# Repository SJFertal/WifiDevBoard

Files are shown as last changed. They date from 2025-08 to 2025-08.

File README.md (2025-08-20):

STM32 based development board with 2.4Ghz communication capabilities

This board serves as my first experience with RF PCB design. This PCB has features such as: -Linear power regulation for low noise power supply -Proper impedance traces for RF and diff pair signal integrity -4 layers for consistent power plane coupling on signal layers 
-ESD protection for input signals 
-Proper antenna isolation 
-Signal layer ground pour and high stitching via count to reduce etching and improve coupling 
-Multiple GPIOs for application breadth 
MCU: STM32G47CB Transciever: NRF24L01P Regulator: LD1117

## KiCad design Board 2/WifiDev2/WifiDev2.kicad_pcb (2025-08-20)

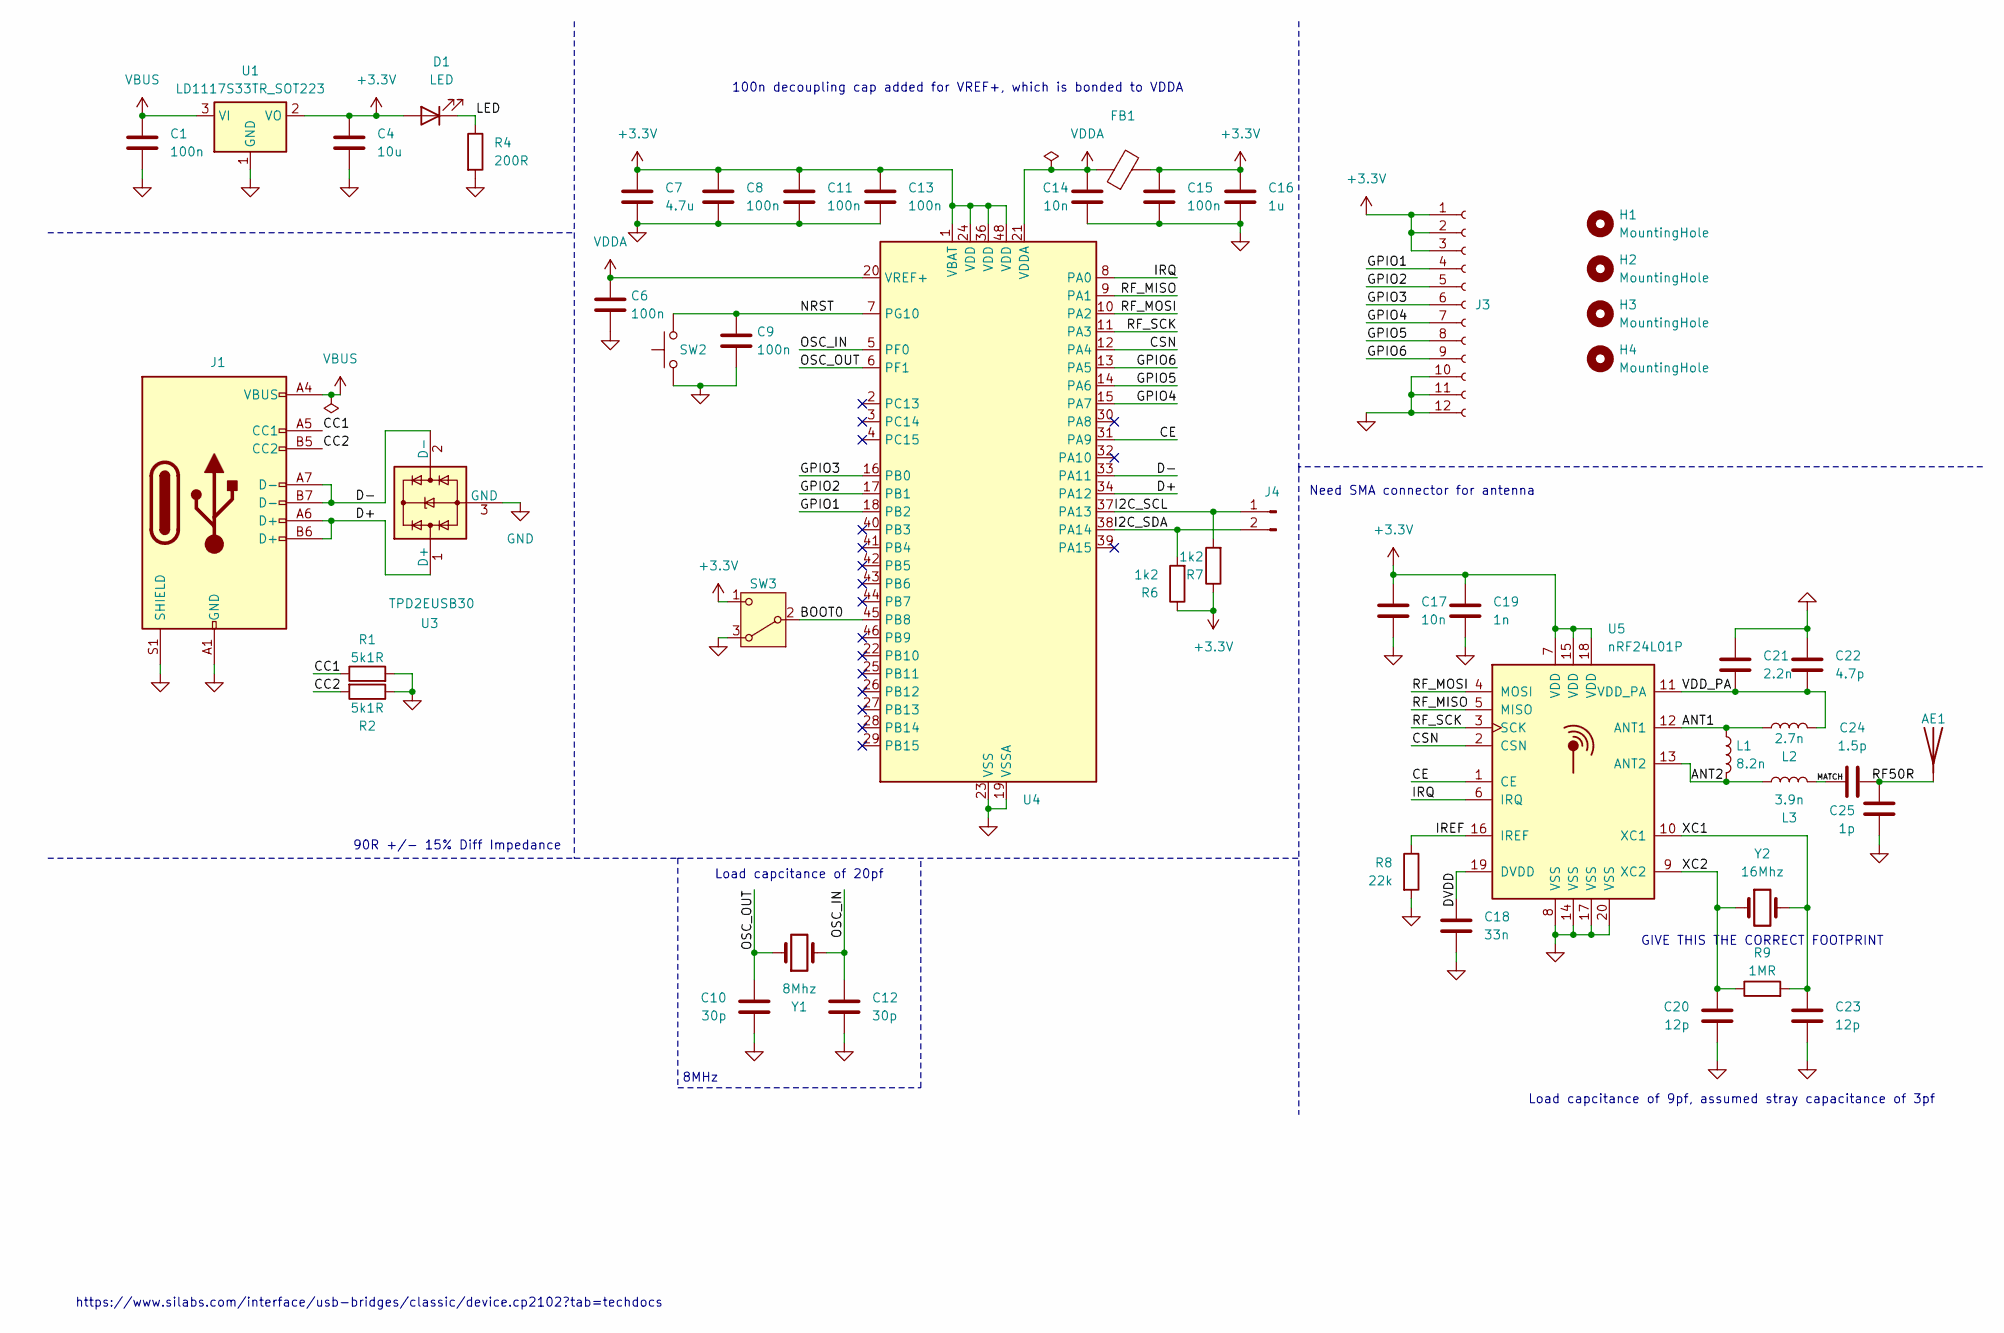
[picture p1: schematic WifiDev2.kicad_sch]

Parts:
AE1: Antenna; AMCA31-2R450G-S1F-T3
C1, C6, C8, C9, C11, C13, C15: 100n; C_0603_1608Metric
C4: 10u; C_0805_2012Metric
C7: 4.7u; C_0805_2012Metric
C10, C12: 30p; C_0603_1608Metric
C14, C17: 10n; C_0603_1608Metric
C16: 1u; C_0805_2012Metric
C18: 33n; C_0603_1608Metric
C19: 1n; C_0603_1608Metric
C20, C23: 12p; C_0603_1608Metric
C21: 2.2n; C_0603_1608Metric
C22: 4.7p; C_0603_1608Metric
C24: 1.5p; C_0603_1608Metric
C25: 1p; C_0603_1608Metric
D1: LED; LED_0603_1608Metric
FB1: FerriteBead; L_0603_1608Metric
H1, H2, H3, H4: MountingHole; MountingHole_2.2mm_M2_DIN965_Pad
J1: USB_C_Receptacle_USB2.0_14P; USB_C_Receptacle_G-Switch_GT-USB-7010ASV
J3: Conn_01x12_Socket; PinSocket_1x12_P2.54mm_Vertical
J4: Conn_01x02_Pin; PinHeader_1x02_P2.54mm_Vertical
L1: 8.2n; L_0603_1608Metric
L2: 2.7n; L_0603_1608Metric
L3: 3.9n; L_0603_1608Metric
R1, R2: 5k1R; R_0603_1608Metric
R4: 200R; R_0603_1608Metric
R6, R7: 1k2; R_0603_1608Metric
R8: 22k; R_0603_1608Metric
R9: 1MR; R_0805_2012Metric
SW2: SW_Push; SW_SPST_PTS647_Sx38
SW3: SW_Nidec_CAS-120A1; Nidec_Copal_CAS-120A
U1: LD1117S33TR_SOT223; SOT-223-3_TabPin2
U3: TPD2EUSB30; Texas_DRT-3
U4: STM32G4A1CETx; LQFP-48_7x7mm_P0.5mm
U5: nRF24L01P; QFN-20-1EP_4x4mm_P0.5mm_EP2.5x2.5mm
Y1: 8Mhz; Crystal_SMD_4Pin_3.2x2.5mm
Y2: 16Mhz; Crystal_SMD_4Pin_3.2x2.5mm

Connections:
+3.3V: C4.1, C7.1, C8.1, C11.1, C13.1, C15.1, C16.1, C17.1, C19.1, D1.2 (A), FB1.2, J3.1, J3.2, J3.3, R6.1, R7.1, SW3.1 (C), U1.2 (VO), U4.1 (VBAT), U4.24 (VDD), U4.36 (VDD), U4.48 (VDD), U5.7 (VDD), U5.15 (VDD), U5.18 (VDD)
/ANT1: L1.1, L2.2, U5.12 (ANT1)
/ANT2: L1.2, L3.2, U5.13 (ANT2)
/BOOT0: SW3.2 (B), U4.45 (PB8)
/CC1: J1.A5 (CC1), R1.1
/CC2: J1.B5 (CC2), R2.2
/CE: U4.31 (PA9), U5.1 (CE)
/CSN: U4.12 (PA4), U5.2 (CSN)
/D+: J1.A6 (D+), J1.B6 (D+), U3.1 (D+), U4.34 (PA12)
/D-: J1.A7 (D-), J1.B7 (D-), U3.2 (D-), U4.33 (PA11)
/DVDD: C18.1, U5.19 (DVDD)
/GPIO1: J3.4, U4.18 (PB2)
/GPIO2: J3.5, U4.17 (PB1)
/GPIO3: J3.6, U4.16 (PB0)
/GPIO4: J3.7, U4.15 (PA7)
/GPIO5: J3.8, U4.14 (PA6)
/GPIO6: J3.9, U4.13 (PA5)
/I2C_SCL: J4.1, R7.2, U4.37 (PA13)
/I2C_SDA: J4.2, R6.2, U4.38 (PA14)
/IREF: R8.1, U5.16 (IREF)
/IRQ: U4.8 (PA0), U5.6 (IRQ)
/LED: D1.1 (K), R4.1
/MATCH: C24.1, L3.1
/NRST: C9.1, SW2.2, U4.7 (PG10)
/OSC_IN: C12.1, U4.5 (PF0), Y1.2
/OSC_OUT: C10.1, U4.6 (PF1), Y1.1
/RF50R: AE1.1 (A), C24.2, C25.1
/RF_MISO: U4.9 (PA1), U5.5 (MISO)
/RF_MOSI: U4.10 (PA2), U5.4 (MOSI)
/RF_SCK: U4.11 (PA3), U5.3 (SCK)
/VDD_PA: C21.2, C22.2, L2.1, U5.11 (VDD_PA)
/XC1: C23.1, R9.2, U5.10 (XC1), Y2.2
/XC2: C20.1, R9.1, U5.9 (XC2), Y2.1
GND: C1.2, C4.2, C6.2, C7.2, C8.2, C9.2, C10.2, C11.2, C12.2, C13.2, C14.2, C15.2, C16.2, C17.2, C18.2, C19.2, C20.2, C21.1, C22.1, C23.2, C25.2, J1.A1 (GND), J1.A12 (GND), J1.B1 (GND), J1.B12 (GND), J1.S1 (SHIELD), J3.10, J3.11, J3.12, R1.2, R2.1, R4.2, R8.2, SW2.1, SW3.3 (A), U1.1 (GND), U3.3 (GND), U4.19 (VSSA), U4.23 (VSS), U4.35 (VSS), U4.47 (VSS), U5.8 (VSS), U5.14 (VSS), U5.17 (VSS), U5.20 (VSS)
VBUS: C1.1, J1.A4 (VBUS), J1.A9 (VBUS), J1.B4 (VBUS), J1.B9 (VBUS), U1.3 (VI)
VDDA: C6.1, C14.1, FB1.1, U4.20 (VREF+), U4.21 (VDDA)

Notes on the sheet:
https://www.silabs.com/interface/usb-bridges/classic/device.cp2102?tab=techdocs
GIVE THIS THE CORRECT FOOTPRINT
8MHz
Need SMA connector for antenna
90R +/- 15% Diff Impedance
Load capcitance of 9pf, assumed stray capacitance of 3pf
100n decoupling cap added for VREF+, which is bonded to VDDA
Load capcitance of 20pf

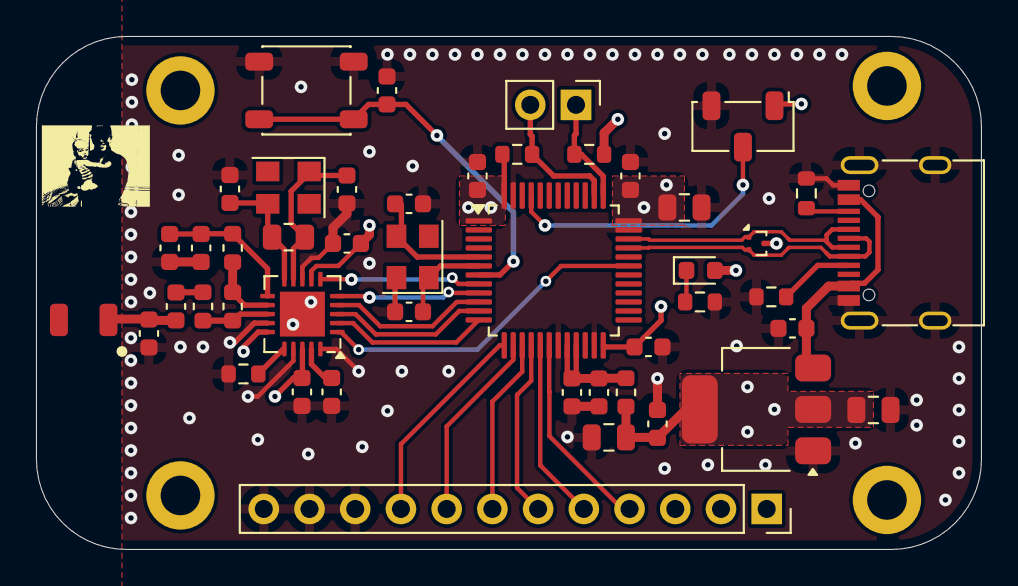
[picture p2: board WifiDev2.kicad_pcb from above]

Board: 4 copper layers, 52.5 x 28.5 mm, 50 parts (0 on the bottom side), 36 nets.

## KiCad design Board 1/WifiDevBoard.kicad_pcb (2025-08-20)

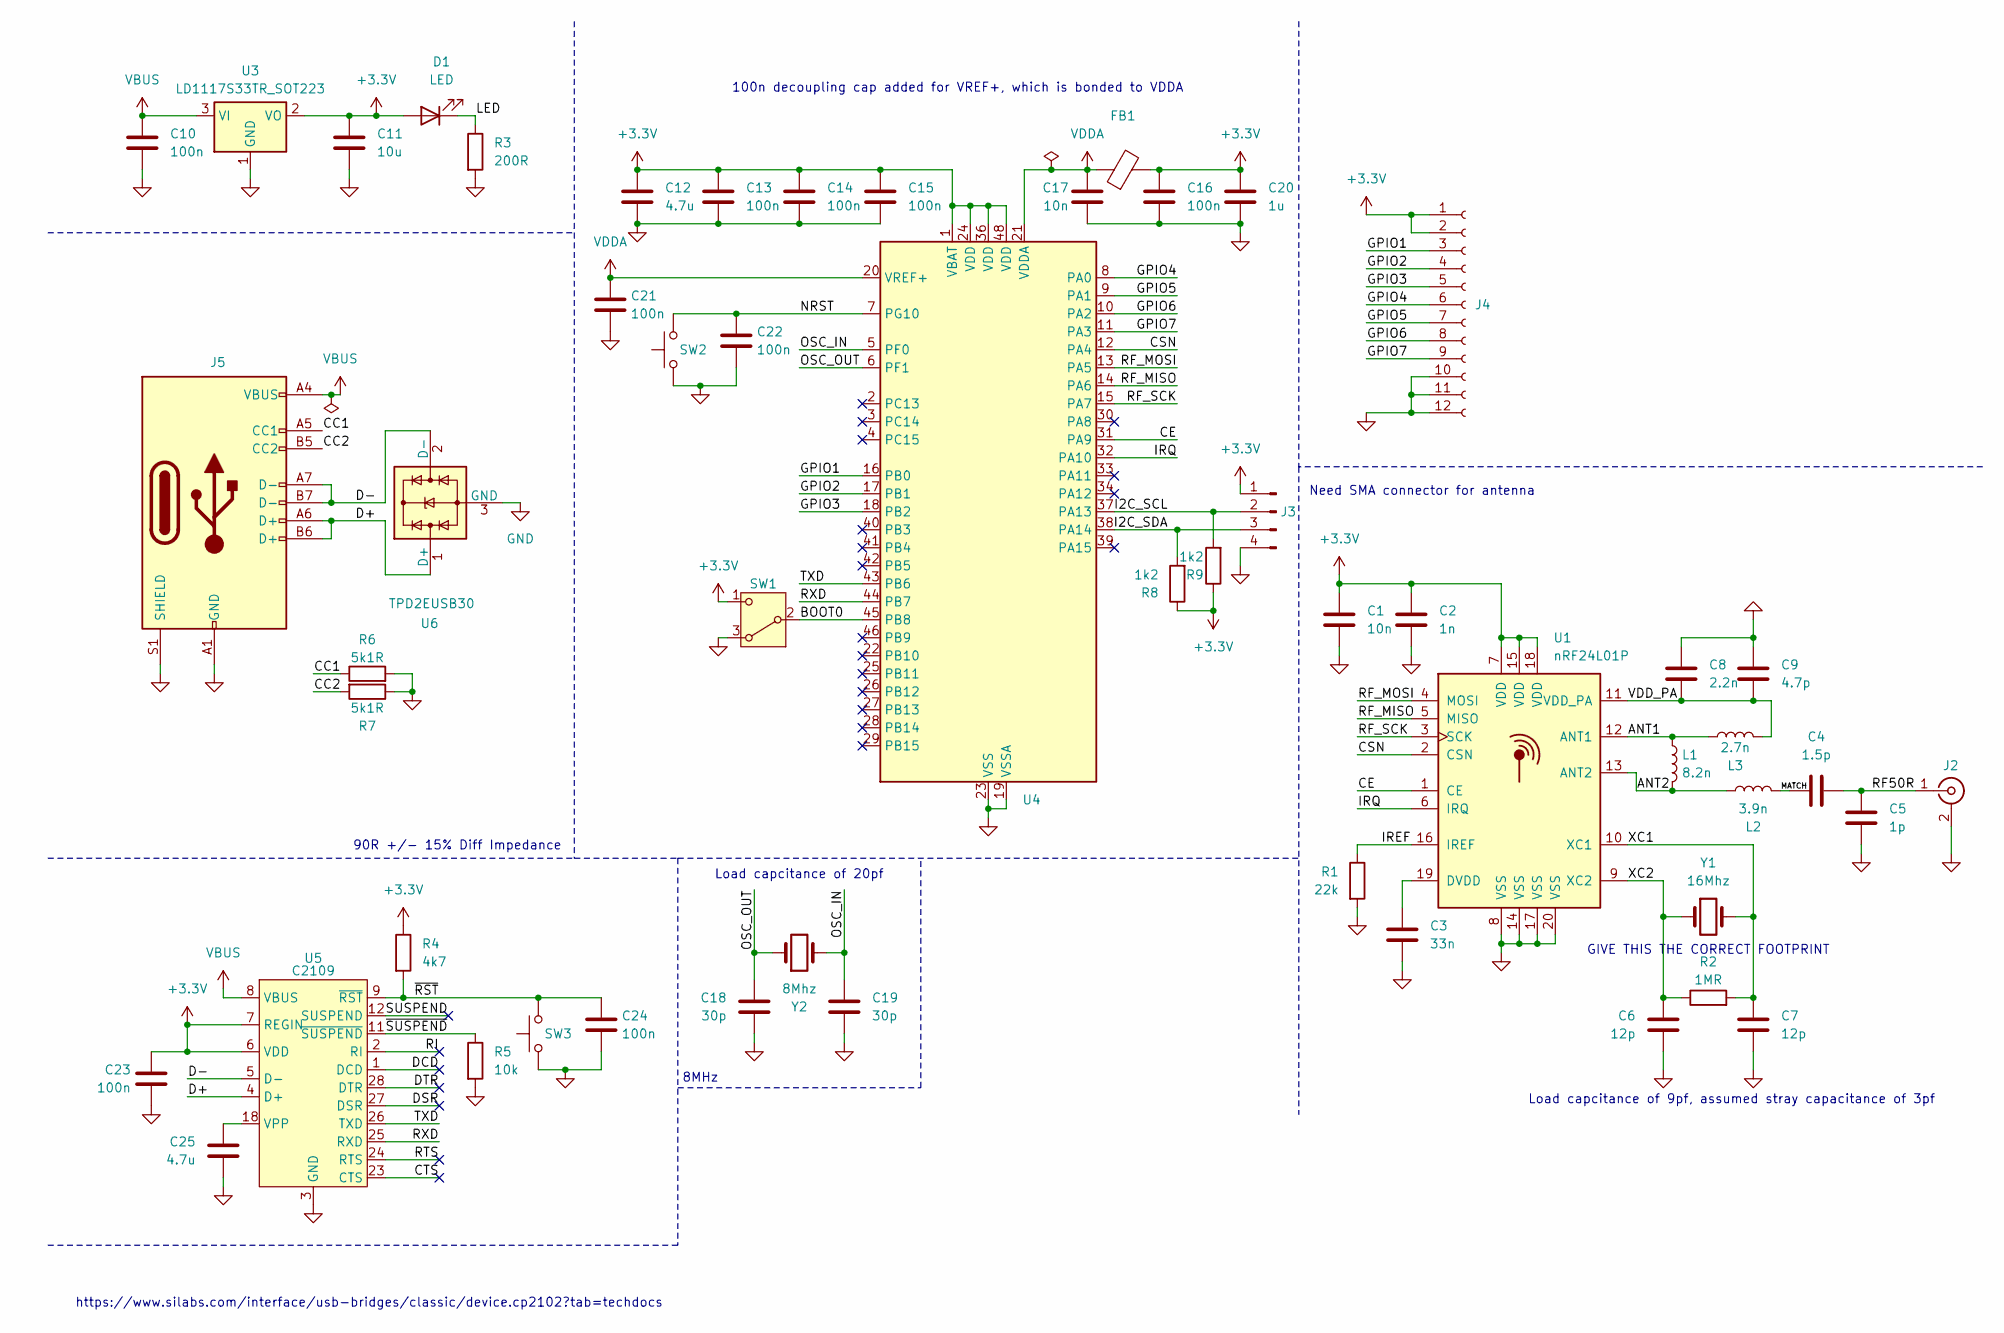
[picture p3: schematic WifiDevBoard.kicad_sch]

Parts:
C1, C17: 10n; C_0603_1608Metric
C2: 1n; C_0603_1608Metric
C3: 33n; C_0603_1608Metric
C4: 1.5p; C_0603_1608Metric
C5: 1p; C_0603_1608Metric
C6, C7: 12p; C_0603_1608Metric
C8: 2.2n; C_0603_1608Metric
C9: 4.7p; C_0603_1608Metric
C10, C13, C14, C15, C16, C21, C22, C23, C24: 100n; C_0603_1608Metric
C11: 10u; C_0805_2012Metric
C12, C25: 4.7u; C_0805_2012Metric
C18, C19: 30p; C_0603_1608Metric
C20: 1u; C_0805_2012Metric
D1: LED; LED_0603_1608Metric
FB1: FerriteBead; L_0603_1608Metric
J2: https://www.mouser.com/ProductDetail/GCT/RFPC-SMA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; SMA_Amphenol_901-144_Vertical
J3: Conn_01x04_Pin; JST_EH_B4B-EH-A_1x04_P2.50mm_Vertical
J4: Conn_01x12_Socket; PinSocket_1x12_P2.54mm_Vertical
J5: USB_C_Receptacle_USB2.0_14P; USB_C_Receptacle_G-Switch_GT-USB-7010ASV
L1: 8.2n; L_0603_1608Metric
L2: 3.9n; L_0603_1608Metric
L3: 2.7n; L_0603_1608Metric
R1: 22k; R_0805_2012Metric
R2: 1MR; R_0805_2012Metric
R3: 200R; R_0805_2012Metric
R4: 4k7; R_0805_2012Metric
R5: 10k; R_0805_2012Metric
R6, R7: 5k1R; R_0805_2012Metric
R8, R9: 1k2; R_0805_2012Metric
SW1: SW_Nidec_CAS-120A1; Nidec_Copal_CAS-120A
SW2, SW3: SW_Push; SW_SPST_PTS647_Sx38
U1: nRF24L01P; QFN-20-1EP_4x4mm_P0.5mm_EP2.5x2.5mm
U3: LD1117S33TR_SOT223; SOT-223-3_TabPin2
U4: STM32G4A1CETx; LQFP-48_7x7mm_P0.5mm
U5: C2109; QFN-28-1EP_5x5mm_P0.5mm_EP3.1x3.1mm
U6: TPD2EUSB30; Texas_DRT-3
Y1: 16Mhz; Crystal_SMD_4Pin_3.2x2.5mm
Y2: 8Mhz; Crystal_SMD_4Pin_3.2x2.5mm

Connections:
+3.3V: C1.1, C2.1, C11.1, C12.1, C13.1, C14.1, C15.1, C16.1, C20.1, C23.1, D1.2 (A), FB1.2, J3.1, J4.1, J4.2, R4.1, R8.1, R9.1, SW1.1 (C), U1.7 (VDD), U1.15 (VDD), U1.18 (VDD), U3.2 (VO), U4.1 (VBAT), U4.24 (VDD), U4.36 (VDD), U4.48 (VDD), U5.6 (VDD), U5.7 (REGIN)
/ANT1: L1.1, L3.2, U1.12 (ANT1)
/ANT2: L1.2, L2.2, U1.13 (ANT2)
/BOOT0: SW1.2 (B), U4.45 (PB8)
/CC1: J5.A5 (CC1), R6.1
/CC2: J5.B5 (CC2), R7.2
/CE: U1.1 (CE), U4.31 (PA9)
/CSN: U1.2 (CSN), U4.12 (PA4)
/CTS: U5.23 (CTS)
/D+: J5.A6 (D+), J5.B6 (D+), U5.4 (D+), U6.1 (D+)
/D-: J5.A7 (D-), J5.B7 (D-), U5.5 (D-), U6.2 (D-)
/DCD: U5.1 (DCD)
/DSR: U5.27 (DSR)
/DTR: U5.28 (DTR)
/GPIO1: J4.3, U4.16 (PB0)
/GPIO2: J4.4, U4.17 (PB1)
/GPIO3: J4.5, U4.18 (PB2)
/GPIO4: J4.6, U4.8 (PA0)
/GPIO5: J4.7, U4.9 (PA1)
/GPIO6: J4.8, U4.10 (PA2)
/GPIO7: J4.9, U4.11 (PA3)
/I2C_SCL: J3.2, R9.2, U4.37 (PA13)
/I2C_SDA: J3.3, R8.2, U4.38 (PA14)
/IREF: R1.1, U1.16 (IREF)
/IRQ: U1.6 (IRQ), U4.32 (PA10)
/LED: D1.1 (K), R3.1
/MATCH: C4.1, L2.1
/NRST: C22.1, SW2.2, U4.7 (PG10)
/OSC_IN: C19.1, U4.5 (PF0), Y2.2
/OSC_OUT: C18.1, U4.6 (PF1), Y2.1
/RF50R: C4.2, C5.1, J2.1 (In)
/RF_MISO: U1.5 (MISO), U4.14 (PA6)
/RF_MOSI: U1.4 (MOSI), U4.13 (PA5)
/RF_SCK: U1.3 (SCK), U4.15 (PA7)
/RI: U5.2 (RI)
/RTS: U5.24 (RTS)
/RXD: U4.44 (PB7), U5.25 (RXD)
/SUSPEND: U5.12 (SUSPEND)
/TXD: U4.43 (PB6), U5.26 (TXD)
/VDD_PA: C8.2, C9.2, L3.1, U1.11 (VDD_PA)
/XC1: C7.1, R2.2, U1.10 (XC1), Y1.2
/XC2: C6.1, R2.1, U1.9 (XC2), Y1.1
/~RST: C24.1, R4.2, SW3.2, U5.9 (~RST)
/~SUSPEND: R5.1, U5.11 (~SUSPEND)
GND: C1.2, C2.2, C3.2, C5.2, C6.2, C7.2, C8.1, C9.1, C10.2, C11.2, C12.2, C13.2, C14.2, C15.2, C16.2, C17.2, C18.2, C19.2, C20.2, C21.2, C22.2, C23.2, C24.2, C25.2, J2.2 (Ext), J3.4, J4.10, J4.11, J4.12, J5.A1 (GND), J5.A12 (GND), J5.B1 (GND), J5.B12 (GND), J5.S1 (SHIELD), R1.2, R3.2, R5.2, R6.2, R7.1, SW1.3 (A), SW2.1, SW3.1, U1.8 (VSS), U1.14 (VSS), U1.17 (VSS), U1.20 (VSS), U3.1 (GND), U4.19 (VSSA), U4.23 (VSS), U4.35 (VSS), U4.47 (VSS), U5.3 (GND), U6.3 (GND), Y1.3, Y1.4, Y2.3, Y2.4
unnamed: C3.1, U1.19 (DVDD)
unnamed: C25.1, U5.18 (VPP)
VBUS: C10.1, J5.A4 (VBUS), J5.A9 (VBUS), J5.B4 (VBUS), J5.B9 (VBUS), U3.3 (VI), U5.8 (VBUS)
VDDA: C17.1, C21.1, FB1.1, U4.20 (VREF+), U4.21 (VDDA)

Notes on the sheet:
100n decoupling cap added for VREF+, which is bonded to VDDA
GIVE THIS THE CORRECT FOOTPRINT
Load capcitance of 9pf, assumed stray capacitance of 3pf
Load capcitance of 20pf
90R +/- 15% Diff Impedance
8MHz
Need SMA connector for antenna
https://www.silabs.com/interface/usb-bridges/classic/device.cp2102?tab=techdocs

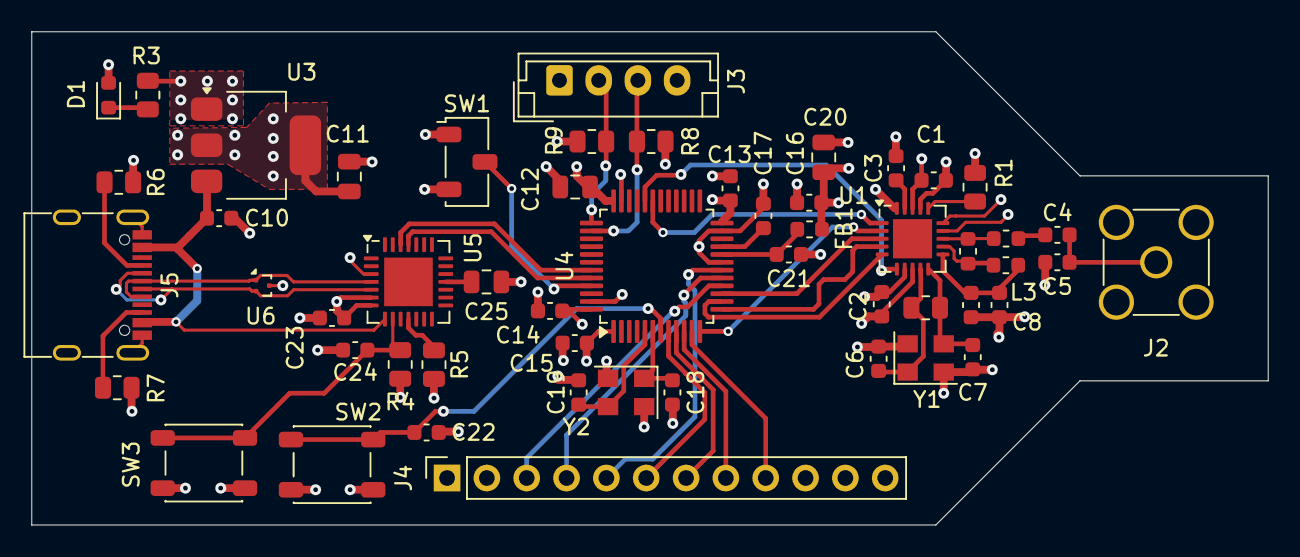
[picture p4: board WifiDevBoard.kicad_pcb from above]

Board: 4 copper layers, 78.8 x 31.4 mm, 53 parts (0 on the bottom side), 42 nets.
